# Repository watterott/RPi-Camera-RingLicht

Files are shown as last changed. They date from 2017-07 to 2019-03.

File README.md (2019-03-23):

# RPi-Camera-RingLicht
Camera Light for Raspberry Pi camera v1 and v2.

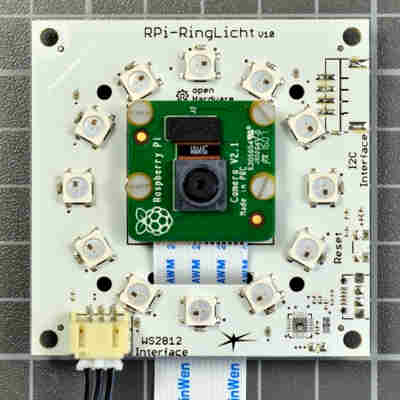
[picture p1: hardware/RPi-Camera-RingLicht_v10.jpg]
RPi-Camera-RingLicht


* 12x WS2812 RGB-LED with built-in controller with serial interface
* Open-Source and released under the [Creative Commons Attribution Share-Alike License](https://creativecommons.org/licenses/by-sa/4.0/).
* **[Documentation on learn.watterott.com](https://learn.watterott.com)**

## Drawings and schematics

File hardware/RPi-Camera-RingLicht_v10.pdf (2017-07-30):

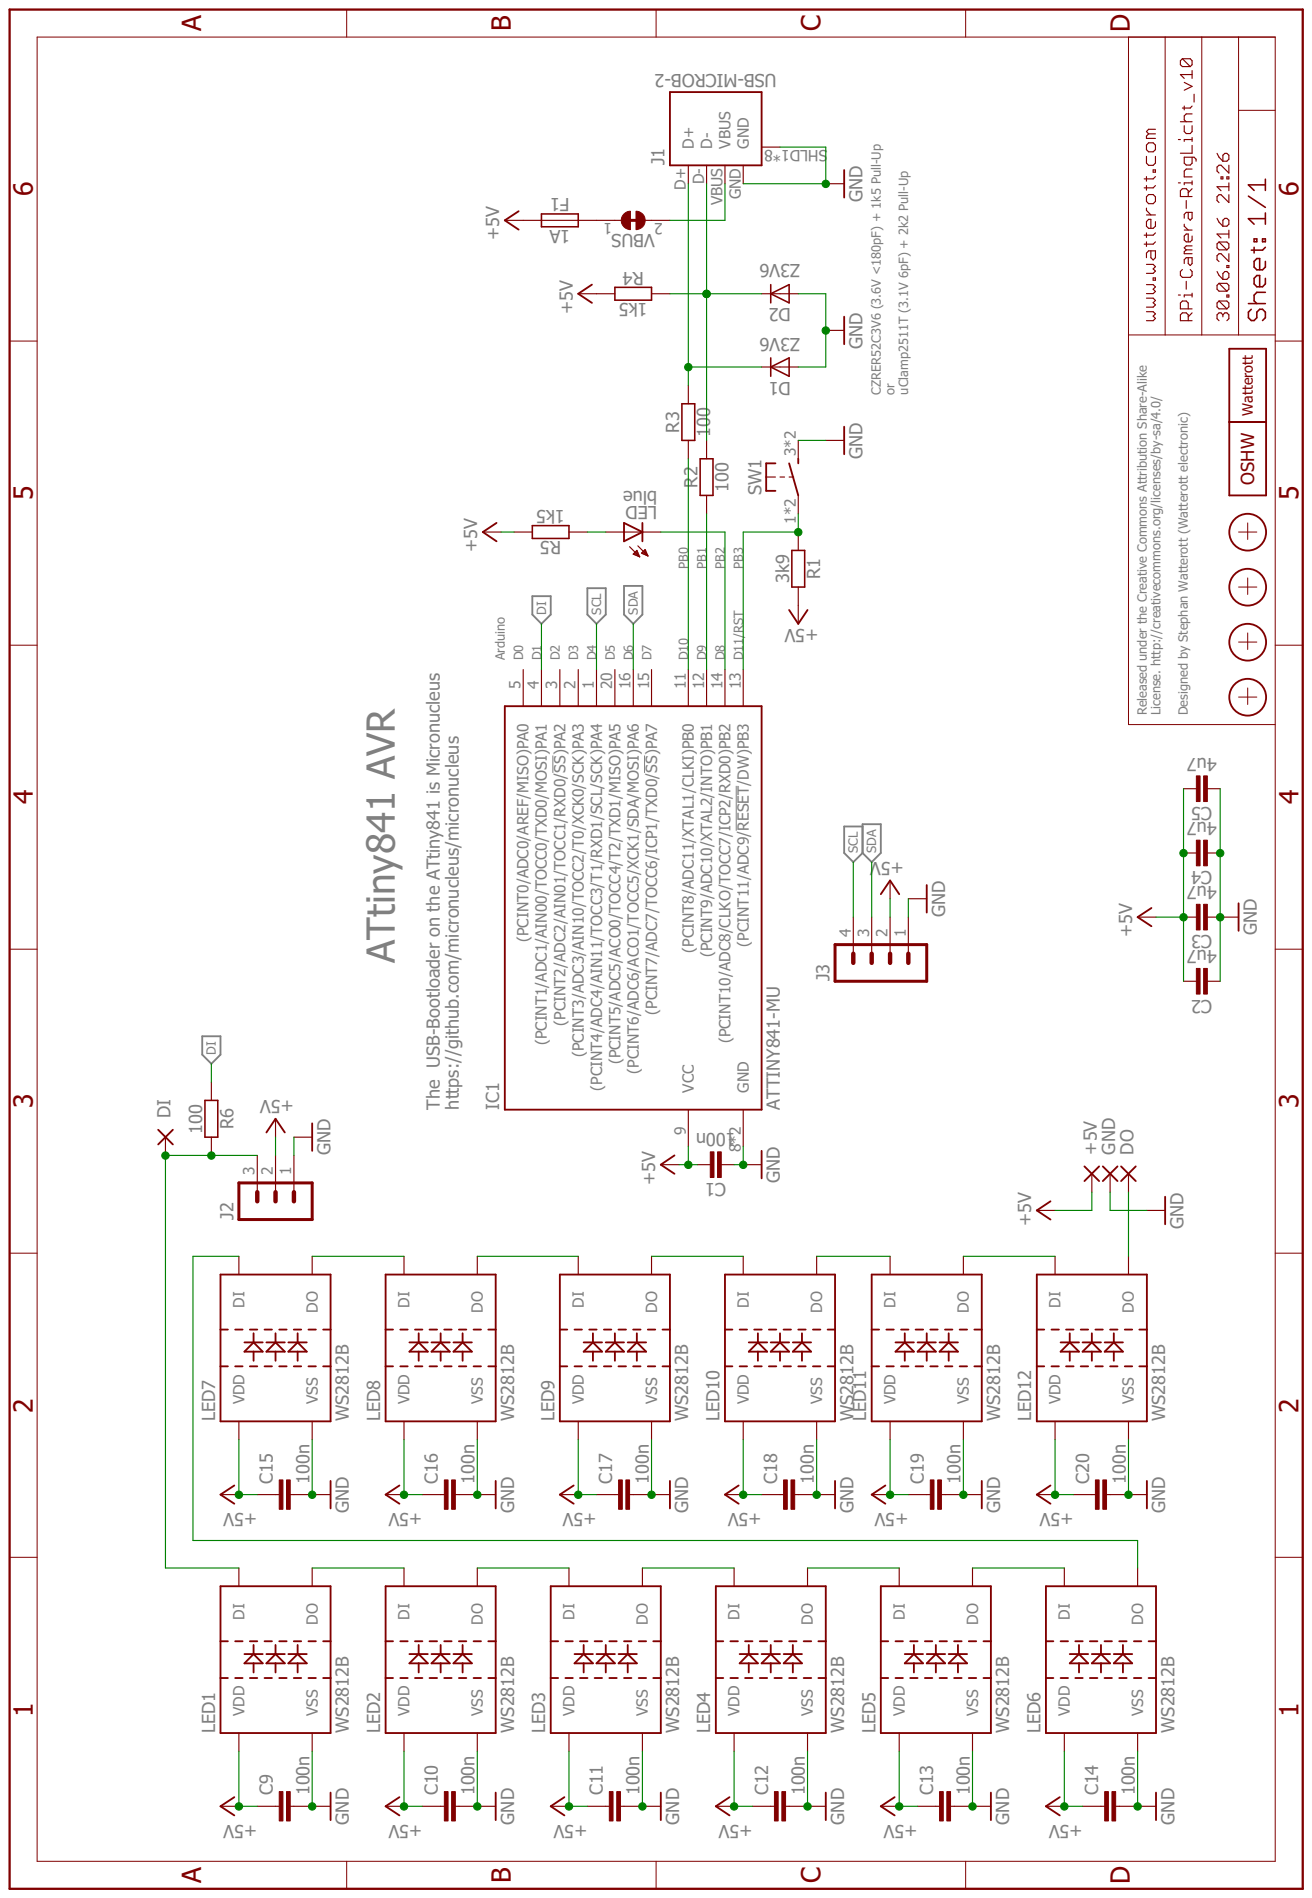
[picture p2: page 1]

Released under the Creative Commons Attribution Share-Alike

License. http://creativecommons.org/licenses/by-sa/4.0/ Designed by Stephan Watterott (Watterott electronic)

The USB-Bootloader on the ATtiny841 is Micronucleus https://github.com/micronucleus/micronucleus

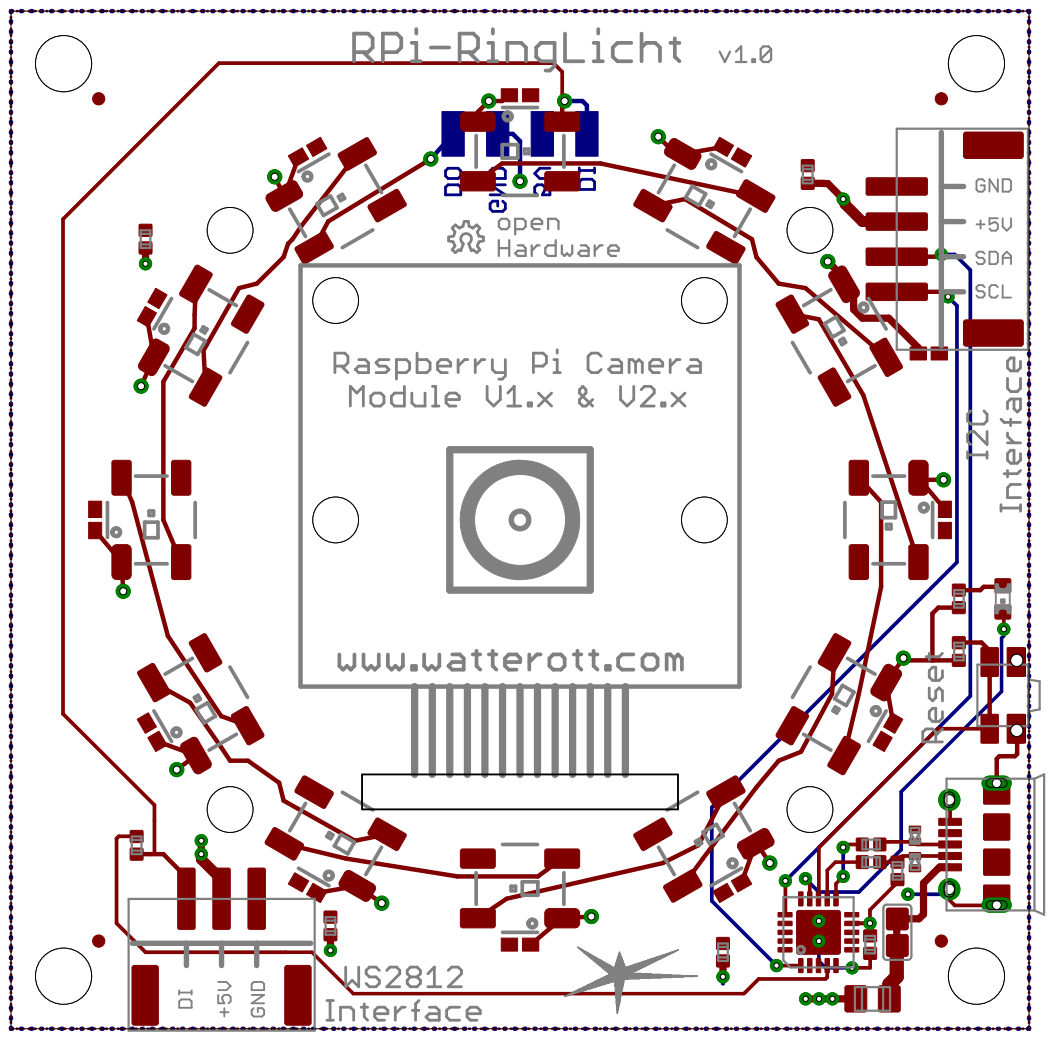
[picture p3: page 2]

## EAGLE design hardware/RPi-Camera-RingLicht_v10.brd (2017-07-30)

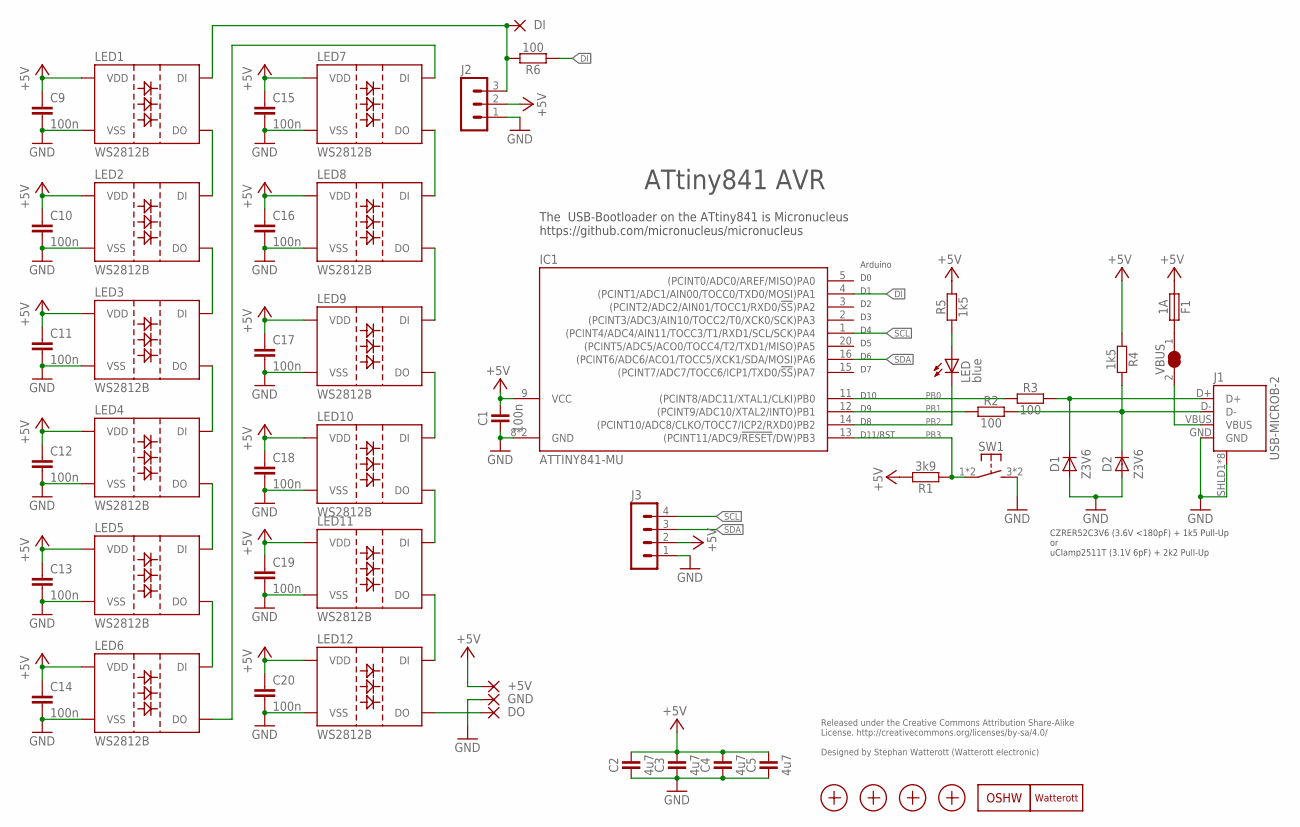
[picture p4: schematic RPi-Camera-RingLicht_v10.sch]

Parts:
+5V: SMD2; SMD1,27-2,54
C1: 100n; C0402
C2, C3, C4, C5: 4u7; C0402
C9, C10, C11, C12, C13, C14, C15, C16, C17, C18, C19, C20: 100n; C0402K
D1, D2: Z3V6; SOD882
DI: SMD2; SMD1,27-2,54
DO: SMD2; SMD1,27-2,54
F1: 1A; C0805
GND: SMD2; SMD1,27-2,54
IC1: ATTINY841-MU; QFN20-PAD
J1: USB-MICROB-2; USB-MICROB-10118194
J2: JST3-S3B-PH-SM4-TB; JST_S3B-PH-SM4-TB
J3: JST4-S4B-PH-SM4-TB; JST_S4B-PH-SM4-TB
LED: blue; C0603
LED1, LED2, LED3, LED4, LED5, LED6, LED7, LED8, LED9, LED10, LED11, LED12: WS2812B
LOGO1: LOGO-S_PLACE_M; SPARK_TPLACE_M
LOGO2: OSHW_LOGOX0070; OSHW_6X70
R1: 3k9; C0402
R2, R3, R6: 100; C0402
R4, R5: 1k5; C0402
SW1: SW-TACTILE-PTS840P; PTS840P
VBUS: JUMPER2-0603-NC; JUMPER2-0603_NC
X1, X2, X3, X4: PASSER-07; PASSER_07MM

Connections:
+5V: +5V.1, C1.2, C2.2, C3.2, C4.2, C5.2, C9.1, C10.1, C11.1, C12.1, C13.1, C14.1, C15.1, C16.1, C17.1, C18.1, C19.1, C20.1, F1.1, IC1.9 (VCC), J2.2, J3.2, LED1.1 (VDD), LED2.1 (VDD), LED3.1 (VDD), LED4.1 (VDD), LED5.1 (VDD), LED6.1 (VDD), LED7.1 (VDD), LED8.1 (VDD), LED9.1 (VDD), LED10.1 (VDD), LED11.1 (VDD), LED12.1 (VDD), R1.2, R4.1, R5.2
DI: IC1.4 ((PCINT1/ADC1/AIN00/TOCC0/TXD0/MOSI)PA1), R6.1
D_N: D2.C, J1.D-, R2.2, R4.2
D_P: D1.C, J1.D+, R3.2
GND: C1.1, C2.1, C3.1, C4.1, C5.1, C9.2, C10.2, C11.2, C12.2, C13.2, C14.2, C15.2, C16.2, C17.2, C18.2, C19.2, C20.2, D1.A, D2.A, GND.1, IC1.8 (GND), IC1.TP (GND), J1.GND, J1.SHLD1 (SHIELD), J1.SHLD2 (SHIELD), J1.SHLD3 (SHIELD), J1.SHLD4 (SHIELD), J1.SHLD5 (SHIELD), J1.SHLD6 (SHIELD), J1.SHLD7 (SHIELD), J1.SHLD8 (SHIELD), J2.1, J3.1, LED1.3 (VSS), LED2.3 (VSS), LED3.3 (VSS), LED4.3 (VSS), LED5.3 (VSS), LED6.3 (VSS), LED7.3 (VSS), LED8.3 (VSS), LED9.3 (VSS), LED10.3 (VSS), LED11.3 (VSS), LED12.3 (VSS), SW1.3 (S1), SW1.4 (S1)
LED+: LED.A, R5.1
unnamed: F1.2, VBUS.1
unnamed: LED1.2 (DO), LED2.4 (DI)
unnamed: LED2.2 (DO), LED3.4 (DI)
unnamed: LED3.2 (DO), LED4.4 (DI)
unnamed: LED4.2 (DO), LED5.4 (DI)
unnamed: LED5.2 (DO), LED6.4 (DI)
unnamed: LED6.2 (DO), LED7.4 (DI)
unnamed: LED7.2 (DO), LED8.4 (DI)
unnamed: LED9.2 (DO), LED10.4 (DI)
unnamed: LED10.2 (DO), LED11.4 (DI)
unnamed: LED11.2 (DO), LED12.4 (DI)
unnamed: LED8.2 (DO), LED9.4 (DI)
unnamed: DI.1, J2.3, LED1.4 (DI), R6.2
unnamed: DO.1, LED12.2 (DO)
PB0: IC1.11 ((PCINT8/ADC11/XTAL1/CLKI)PB0), R3.1
PB1: IC1.12 ((PCINT9/ADC10/XTAL2/INTO)PB1), R2.1
PB2: IC1.14 ((PCINT10/ADC8/CLKO/TOCC7/ICP2/RXD0)PB2), LED.C
PB3: IC1.13 ((PCINT11/ADC9/!RESET!/DW)PB3), R1.1, SW1.1, SW1.2 (P1)
SCL: IC1.1 ((PCINT4/ADC4/AIN11/TOCC3/T1/RXD1/SCL/SC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), J3.4
SDA: IC1.16 ((PCINT6/ADC6/ACO1/TOCC5/XCK1/SDA/MOSI)P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), J3.3
VBUS1: J1.VBUS, VBUS.2

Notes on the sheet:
Released under the Creative Commons Attribution Share-Alike License. http://creativecommons.org/licenses/by-sa/4.0/ Designed by Stephan Watterott (Watterott electronic)
The USB-Bootloader on the ATtiny841 is Micronucleus https://github.com/micronucleus/micronucleus
CZRER52C3V6 (3.6V <180pF) + 1k5 Pull-Up or uClamp2511T (3.1V 6pF) + 2k2 Pull-Up
ATtiny841 AVR
Arduino
D10
D11/RST

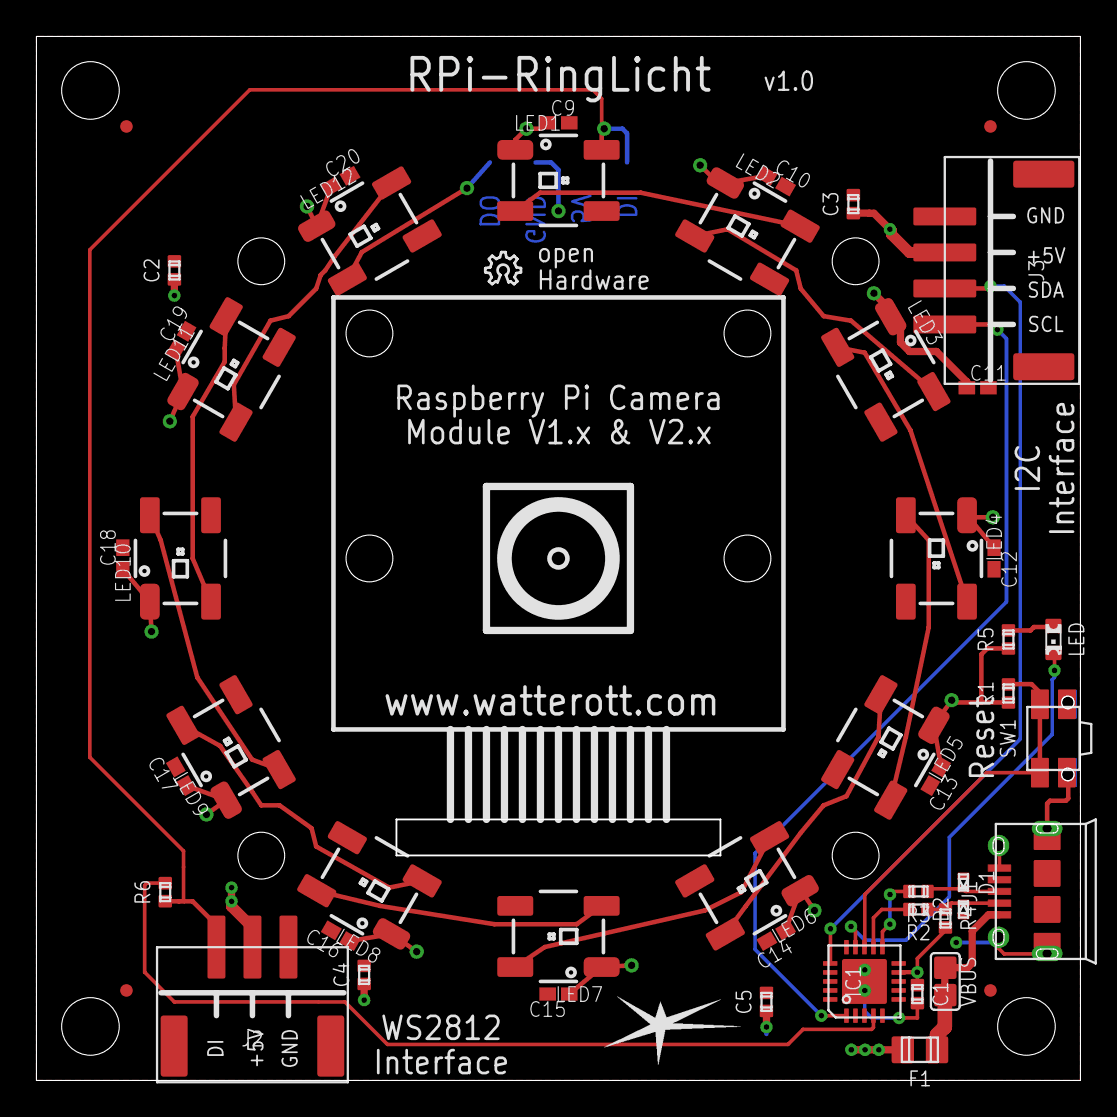
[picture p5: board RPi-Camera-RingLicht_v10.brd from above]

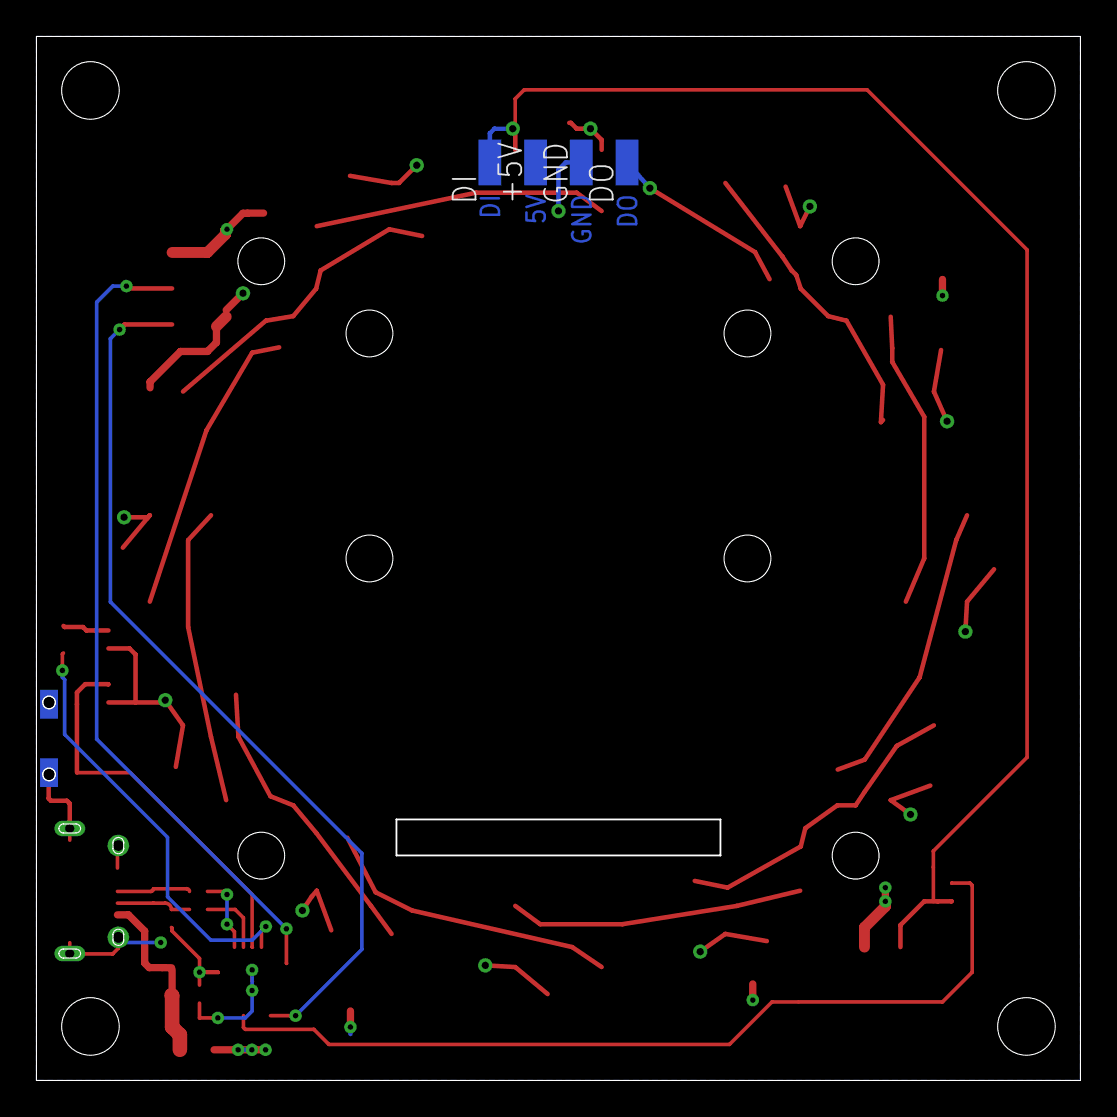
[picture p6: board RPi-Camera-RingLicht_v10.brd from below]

Board: 2 copper layers, 58.0 x 58.0 mm, 55 parts (4 on the bottom side), 27 nets.
